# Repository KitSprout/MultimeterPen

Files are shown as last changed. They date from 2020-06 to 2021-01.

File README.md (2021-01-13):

[MultimeterPen](https://github.com/KitSprout/MultimeterPen)
========



陽春版的電表筆只能測量短斷路和電壓，設計主要以輕巧、便利、低成本為主，使用 STM32L011F4U6 的芯片，尺寸 3x3mm 的 MCU速度夠價格也很便宜，唯一的缺點就是只有 2K 的 RAM。

View
========
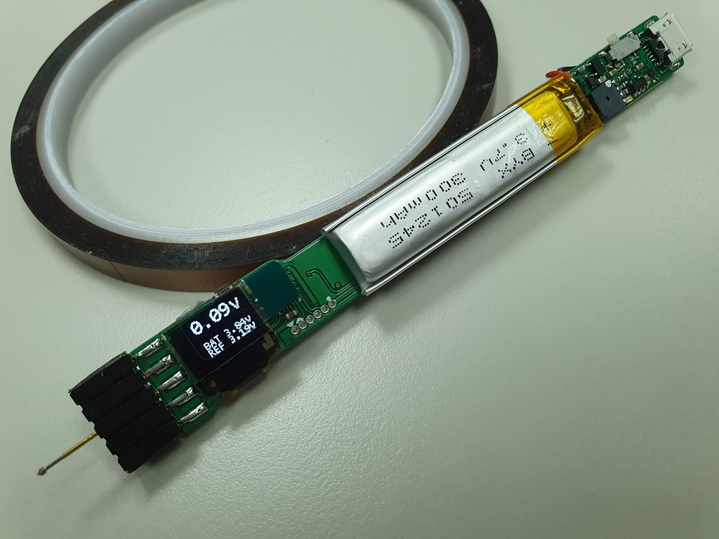
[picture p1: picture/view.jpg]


[more photo](https://photos.app.goo.gl/xKgrYJPt2BU4r5Fe8)

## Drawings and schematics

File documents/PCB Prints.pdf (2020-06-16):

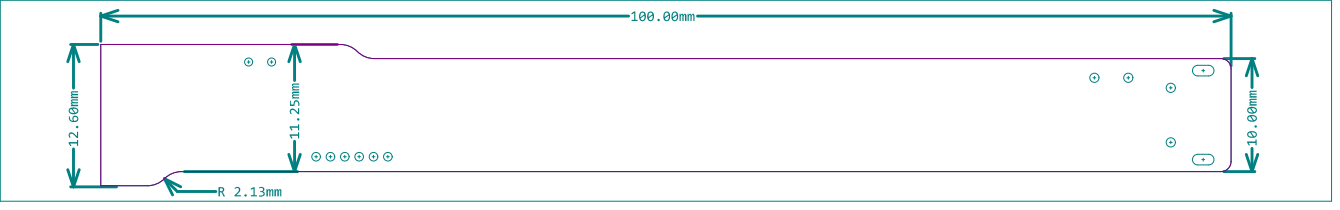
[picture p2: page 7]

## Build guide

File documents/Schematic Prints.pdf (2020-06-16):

# MultimeterPen

# LEVEL SHIFTER

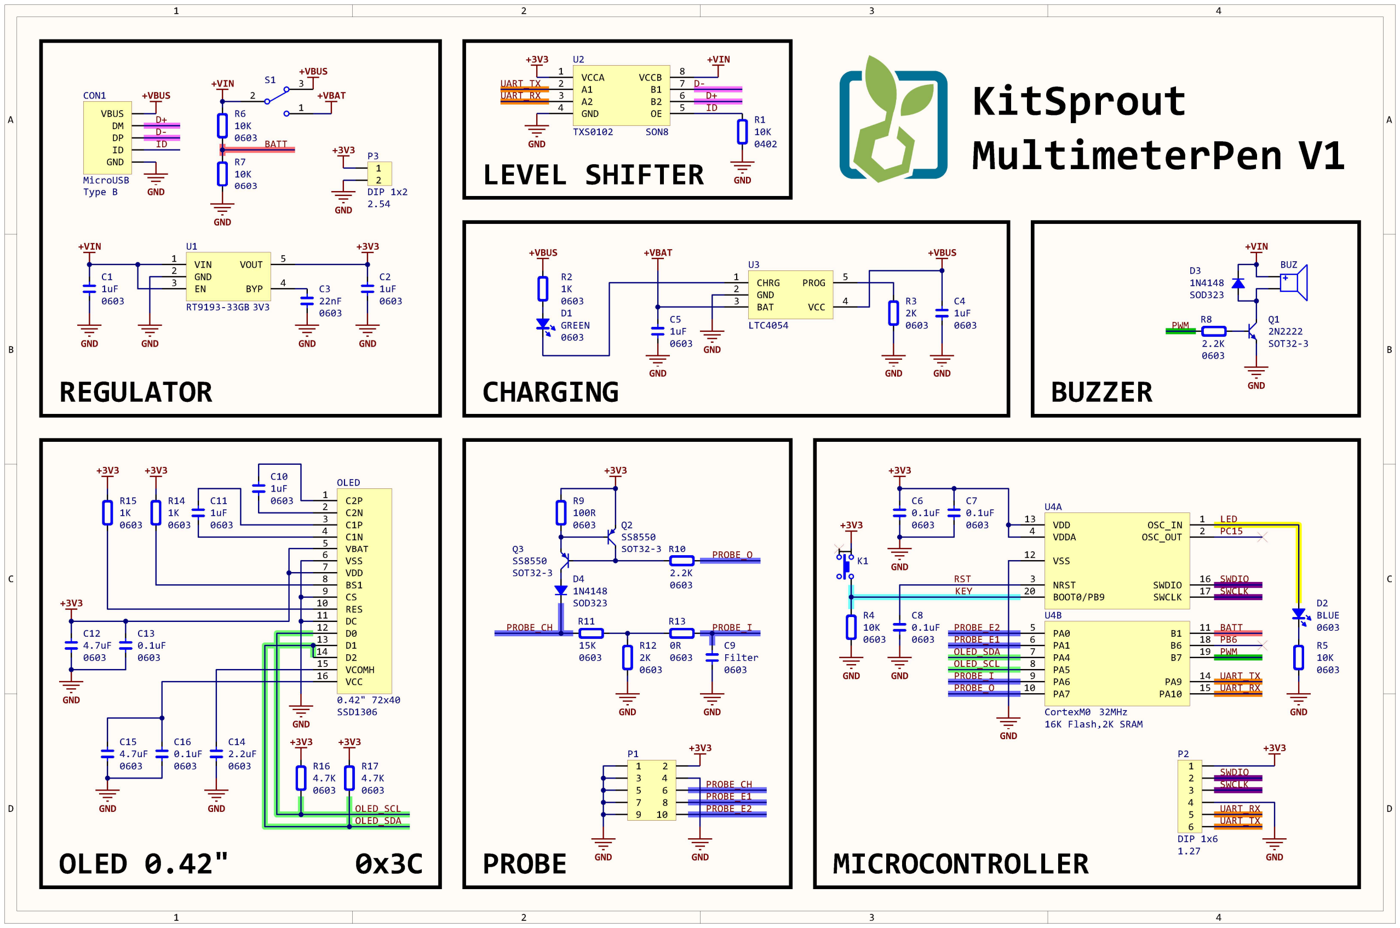
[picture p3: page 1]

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
0603

BLUE

D2

0603

10K

R4

Type B

VBUS
DM
DP
ID
GND

CON1

MicroUSB

DIP 1x6
1.27

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
0603

C10

1uF
0603

C11

GND

0603

1K

R14

+3V3

+3V3

4.7uF
0603

C12
0.1uF
0603

C13

GND

0603

1K

R15

+3V3

2.2uF
0603

C14

GND

4.7uF
0603

C15
0.1uF
0603

C16

GND | OLED_SCL OLED_SDA

+VBUS

+VIN

GND

1uF
0603

C1

GND

1uF
0603

C2

+3V3

GND

3V3

VIN 1
GND 2
EN 3
BYP | 4
VOUT | 5

U1

RT9193-33GB | 22nF
| 0603

C3

GND | GND

PWM

ID

KEY

SON8

VCCA 1
A1 2
A2 3
GND 4
OE | 5
B2 | 6
B1 | 7
VCCB | 8

U2

TXS0102

+3V3

GND

UART_TX
UART_RX

GND

D-

D+
D-

+VIN

UART_TX
UART_RX

D+

0402

10K

R1

GND | 0603 10K

R5

GND

UART_RX

GND

+3V3

SWDIO
SWCLK

SWDIO
PROBE_CH | SWCLK

+VBUS

+VBUS

+VBAT

0603

100R

R9

+3V3

PROBE_O

PROBE_CH

0603

2.2K

R10

0603

15K

R11

0603

2K

R12
0603

0R

R13

SS8550
SOT32-3

Q2

SS8550
SOT32-3

Q3

1N4148
SOD323

D4

GND

Filter
0603

C9

GND

PROBE_I

CHRG 1
GND 2
BAT 3
VCC | 4
PROG | 5

U3

LTC4054 | 0603 2K

0603 R3

1K

R2

GND GND

1uF
0603

C4

1uF
0603

C5
0603

GREEN

D1

GND

+3V3
1 2
3 4
5 6
7 8
9 10

P1

GND

PROBE_E2

PWM

0603

10K

R7

0603

10K

R6

+VIN

GND

BATT

2N2222
SOT32-3

Q1

0603

2.2K

R8

+VIN

GND

0603

4.7K

R16

0603

4.7K

R17

+3V3 +3V3

UART_TX

1N4148
SOD323

D3

0.1uF
0603

C7
0.1uF
0603

C6

GND

GND

RST

+3V3

PROBE_E1

BATT

OLED_SCL

OLED_SDA

PROBE_I
PROBE_O

0.1uF
0603

C8

GND

LED +3V3

PB6

PC15

K1

2

3

1

S1

BUZ

0.42" 72x40
SSD1306

C2P 1
C2N 2
C1P 3
C1N 4
VBAT 5
VSS 6
VDD 7
BS1 8
CS 9
RES 10
DC 11
D0 12
D1 13
D2 14
VCOMH 15
VCC 16

OLED

BOOT0/PB9 20

OSC_IN | 1
OSC_OUT | 2

NRST 3

VDDA 4

VSS 12

VDD 13

SWDIO | 16
SWCLK | 17

U4A

CortexM0 32MHz
16K Flash,2K SRAM

PA0 5
PA1 6
PA4 7
PA5 8
PA6 9
PA7 10 | PA9 | 14
| PA10 | 15
| B6 | 18
| B7 | 19
B1 | 11

U4B

1
2
DIP 1x2
2.54

P3

GND

+3V3

OLED 0.42" | PROBE

# BUZZER

+VBUS

GND

GND

# CHARGING

+VBAT

PROBE_E2

PROBE_E1
0x3C | MICROCONTROLLER

ID

# REGULATOR

# KitSprout

V1

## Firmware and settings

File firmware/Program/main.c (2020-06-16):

/**
 *      __            ____
 *     / /__ _  __   / __/                      __  
 *    / //_/(_)/ /_ / /  ___   ____ ___  __ __ / /_ 
 *   / ,<  / // __/_\ \ / _ \ / __// _ \/ // // __/ 
 *  /_/|_|/_/ \__//___// .__//_/   \___/\_,_/ \__/  
 *                    /_/   github.com/KitSprout    
 * 
 *  @file    main.c
 *  @author  KitSprout
 *  @brief   main function
 * 
 */

/* Includes --------------------------------------------------------------------------------*/
#include "kitsprout\kSystem.h"
#include "drivers\stm32l0_adc.h"
#include "modules\serial.h"
#include "modules\ssd1306.h"

#include <stdio.h>
#include "stm32x_bsp.h"

/* Define ----------------------------------------------------------------------------------*/

#define TIMER_TICK_FREQ     (25000)     // 25kHz, 40us
#define UPDATE_FREQ         (500)       // 50Hz

#define MA_WEIGHTING_H      (0.2f)
#define MA_WEIGHTING        (0.5f)

#define SHORT_THRESHOLD     (0.5f)
#define DIODE_THRESHOLD     (1.0f)

/* Macro -----------------------------------------------------------------------------------*/
/* Typedef ---------------------------------------------------------------------------------*/

enum
{
    MODE_VOLTAGE    = 0,
    MODE_SHORT      = 1,
    MODE_DIODE      = 2,
    MODE_COUNT,

} measureMode;

/* Variables -------------------------------------------------------------------------------*/

uint32_t tick = 0;
uint32_t beepcmd = 0;
uint32_t beepcnt = 0;

/* Prototypes ------------------------------------------------------------------------------*/
void event_timer_tick( void );

/* Functions -------------------------------------------------------------------------------*/

void bsp_init( void )
{
    bsp_gpio_init();
    bsp_timer_init(event_timer_tick, TIMER_TICK_FREQ);
    bsp_uart_serial_init(NULL);
    bsp_probe_init();

    delay_ms(200);
    SSD1306_Config();
    delay_ms(200);
    SSD1306_Init();

    bsp_timer_enable(ENABLE);
}

void beep( uint32_t cmd )
{
    beepcmd = cmd;
}

int main( void )
{
    bsp_init();

    uint32_t mode = MODE_VOLTAGE;

    uint16_t vprobeLsb = ADC_GetValue(0);
    uint16_t vbattLsb = ADC_GetValue(1);
    uint16_t VREFINT_DATA = ADC_GetValue(2);
    float vref = 3.0f * VREFINT_CAL / VREFINT_DATA;
    float vbatt = (vbattLsb / 4096.0f) * vref * 2;
    float vprobe = ((vprobeLsb - 50) / 4096.0f) * vref * (17/2.0f);
    float f_vref = vref, f_vbatt = vbatt, f_vprobe = vprobe;

    while (1)
    {
        if (tick >= (TIMER_TICK_FREQ / UPDATE_FREQ))
        {
            tick = 0;

            vprobeLsb = ADC_GetValue(0);
            vbattLsb = ADC_GetValue(1);
            VREFINT_DATA = ADC_GetValue(2);
            vref = 3.0f * VREFINT_CAL / VREFINT_DATA;
            vbatt = (vbattLsb / 4096.0f) * vref * 2;
            vprobe = ((vprobeLsb - 50) / 4096.0f) * vref * (17/2.0f);

            f_vref = (MA_WEIGHTING_H) * vref + (1.0f - MA_WEIGHTING_H) * f_vref;
            f_vbatt = (MA_WEIGHTING_H) * vbatt + (1.0f - MA_WEIGHTING_H) * f_vbatt;
            f_vprobe = (MA_WEIGHTING) * vprobe + (1.0f - MA_WEIGHTING) * f_vprobe;

            if (KEY_READ())
            {
                if (++mode == MODE_COUNT)
                {
                    mode = MODE_VOLTAGE;
                }

                beep(1);
                switch (mode)
                {
                    case MODE_VOLTAGE:
                    {
                        LED_On();
                        delay_ms(250);
                        LED_Off();
                        PROBE_OUT_Off();
                        break;
                    }
                    case MODE_SHORT:
                    {
                        LED_On();
                        delay_ms(250);
                        LED_Off();
                        PROBE_OUT_On();
                        vprobe = 5;
                        break;
                    }
                    case MODE_DIODE:
                    {
                        LED_On();
                        delay_ms(250);
                        LED_Off();
                        PROBE_OUT_On();
                        vprobe = 5;
                        break;
                    }
                }
                beep(0);
            }

            switch (mode)
            {
                case MODE_VOLTAGE:
                {
                    SSD1306_PutVoltage(5, 0, f_vprobe, 1);
                    SSD1306_PutBatteryVoltage(17, 3, f_vbatt, 1);
                    SSD1306_PutReferenceVoltage(17, 4, f_vref, 1);
//                    printf("vin = %.2fv (%6d), probe = %.2fv (%6d), vref = %.2fv (cal %6d, data %6d)\r\n",
//                        vin, vinLsb, probe, probeLsb, vref, VREFINT_CAL, VREFINT_DATA);
                    break;
                }
                case MODE_SHORT:
                {
                    beep(vprobe < SHORT_THRESHOLD);

                    SSD1306_PutVoltage(5, 0, f_vprobe, 1);
                    SSD1306_PutBatteryVoltage(17, 3, f_vbatt, 1);
                    SSD1306_PutReferenceVoltage(17, 4, SHORT_THRESHOLD, 1);
                    break;
                }
                case MODE_DIODE:
                {
                    beep(vprobe < DIODE_THRESHOLD);

                    SSD1306_PutVoltage(5, 0, f_vprobe, 1);
                    SSD1306_PutBatteryVoltage(17, 3, f_vbatt, 1);
                    SSD1306_PutReferenceVoltage(17, 4, DIODE_THRESHOLD, 1);
                    break;
                }
            }
        }
    }
}

void event_timer_tick( void )
{
    tick++;

    if (beepcmd)
    {
        if (++beepcnt > 5)
        {
            beepcnt = 0;
            BUZ_Off();
        }
        else
        {
            BUZ_On();
        }
    }
    else
    {
        beepcnt = 0;
        BUZ_Off();
    }
}

/*************************************** END OF FILE ****************************************/

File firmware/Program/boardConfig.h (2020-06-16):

/**
 *      __            ____
 *     / /__ _  __   / __/                      __  
 *    / //_/(_)/ /_ / /  ___   ____ ___  __ __ / /_ 
 *   / ,<  / // __/_\ \ / _ \ / __// _ \/ // // __/ 
 *  /_/|_|/_/ \__//___// .__//_/   \___/\_,_/ \__/  
 *                    /_/   github.com/KitSprout    
 * 
 *  @file    boardConfig.h
 *  @author  KitSprout
 *  @brief   
 * 
 */

/* Define to prevent recursive inclusion ---------------------------------------------------*/
#ifndef __BOARDCONFIG_H
#define __BOARDCONFIG_H

#ifdef __cplusplus
extern "C" {
#endif

/* Define ----------------------------------------------------------------------------------*/

#define KS_HW_BOARD_NAME                    "NULL"
#define KS_HW_MCU_NAME                      "STM32L011F4"

#define KS_HW_USE_CLOCK_SOUCE_INT           (0U)
#define KS_HW_USE_CLOCK_SOUCE_EXT           (1U)
#define KS_HW_HCLOCK_SOUCE                  KS_HW_USE_CLOCK_SOUCE_INT
#define KS_HW_LCLOCK_SOUCE                  KS_HW_USE_CLOCK_SOUCE_INT

#define KS_FW_UART_HAL_LIBRARY              (0U)
#define KS_FW_I2C_HAL_LIBRARY               (0U)


/* -------- LED and KEY */

#define LED_PIN                             GPIO_PIN_14
#define LED_GPIO_PORT                       GPIOC
#define LED_Set()                           __GPIO_SET(LED_GPIO_PORT, LED_PIN)
#define LED_Reset()                         __GPIO_RST(LED_GPIO_PORT, LED_PIN)
#define LED_Toggle()                        __GPIO_TOG(LED_GPIO_PORT, LED_PIN)
#define LED_On()                            LED_Set()
#define LED_Off()                           LED_Reset()

#define BUZ_PIN                             GPIO_PIN_7
#define BUZ_GPIO_PORT                       GPIOB
#define BUZ_Set()                           __GPIO_SET(BUZ_GPIO_PORT, BUZ_PIN)
#define BUZ_Reset()                         __GPIO_RST(BUZ_GPIO_PORT, BUZ_PIN)
#define BUZ_Toggle()                        __GPIO_TOG(BUZ_GPIO_PORT, BUZ_PIN)
#define BUZ_On()                            BUZ_Set()
#define BUZ_Off()                           BUZ_Reset()

#define KEY_PIN                             GPIO_PIN_9
#define KEY_GPIO_PORT                       GPIOB
#define KEY_READ()                          (__GPIO_READ(KEY_GPIO_PORT, KEY_PIN) == KEY_PIN)


/* -------- TIM Timer */

#define TIMER2                              TIM2
#define TIMER2_CLK_ENABLE()                 __HAL_RCC_TIM2_CLK_ENABLE()
#define TIMER2_IRQn                         TIM2_IRQn
#define TIMER2_TIMx_IRQHandler              TIM2_IRQHandler
#define TIMER2_TIMx_IRQn_PREEMPT            0U
#define TIMER2_TIMx_IRQn_SUB                1U


/* -------- PROBE */

#define ADC_MAX_CHANNEL                     (2U)
#define ADC_MAX_SAMPLEBUF                   (1U)

#define ADCx                                ADC1
#define ADCx_CLK_ENABLE()                   __HAL_RCC_ADC1_CLK_ENABLE()
#define ADCx_DMA_CLK_ENABLE()               __HAL_RCC_DMA1_CLK_ENABLE()
#define ADCx_DMA_CHANNEL                    DMA1_Channel1
#define ADCx_DMA_IRQn                       DMA1_Channel1_IRQn
#define ADCx_DMA_IRQn_PREEMPT               (0U)
#define ADCx_DMA_IRQn_SUB                   (0U)

#define ADCx_CLK_DISABLE()                  __HAL_RCC_ADC1_CLK_DISABLE()
#define ADCx_SAMPLETIME                     ADC_SAMPLETIME_79CYCLES_5

#define ADCx_PROBE_RANK                     1
#define ADCx_PROBE_CHANNEL                  ADC_CHANNEL_6
#define ADCx_PROBE_CHANNEL_PIN              GPIO_PIN_6
#define ADCx_PROBE_CHANNEL_GPIO_PORT        GPIOA

#define ADCx_BATT_RANK                      2
#define ADCx_BATT_CHANNEL                   ADC_CHANNEL_9
#define ADCx_BATT_CHANNEL_PIN               GPIO_PIN_1
#define ADCx_BATT_CHANNEL_GPIO_PORT         GPIOB

#define PROBE_OUT_PIN                       GPIO_PIN_7
#define PROBE_OUT_GPIO_PORT                 GPIOA
#define PROBE_OUT_Set()                     __GPIO_SET(PROBE_OUT_GPIO_PORT, PROBE_OUT_PIN)
#define PROBE_OUT_Reset()                   __GPIO_RST(PROBE_OUT_GPIO_PORT, PROBE_OUT_PIN)
#define PROBE_OUT_Toggle()                  __GPIO_TOG(PROBE_OUT_GPIO_PORT, PROBE_OUT_PIN)
#define PROBE_OUT_On()                      PROBE_OUT_Reset()
#define PROBE_OUT_Off()                     PROBE_OUT_Set()

#define PROBE_EXT1_PIN                      GPIO_PIN_1
#define PROBE_EXT1_GPIO_PORT                GPIOA
#define PROBE_EXT1_Set()                    __GPIO_SET(PROBE_EXT1_GPIO_PORT, PROBE_EXT1_PIN)
#define PROBE_EXT1_Reset()                  __GPIO_RST(PROBE_EXT1_GPIO_PORT, PROBE_EXT1_PIN)
#define PROBE_EXT1_Toggle()                 __GPIO_TOG(PROBE_EXT1_GPIO_PORT, PROBE_EXT1_PIN)
#define PROBE_EXT1_On()                     PROBE_EXT1_Set()
#define PROBE_EXT1_Off()                    PROBE_EXT1_Reset()
#define PROBE_EXT1_READ()                   (__GPIO_READ(PROBE_EXT1_GPIO_PORT, PROBE_EXT1_PIN) == PROBE_EXT1_PIN)
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

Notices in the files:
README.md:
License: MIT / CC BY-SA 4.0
